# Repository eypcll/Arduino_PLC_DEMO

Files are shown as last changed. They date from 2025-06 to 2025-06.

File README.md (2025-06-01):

# Arduino_PLC_DEMO
Demo project for PLC with Arduino Nano
# ÖNSÖZ
PLC'ler (Programmable Logic Controllers), endüstriyel otomasyon süreçlerinde yaygın olarak kullanılan mikroişlemci tabanlı cihazlardır. Fabrika makinelerini, üretim hatlarını ve diğer otomasyon sistemlerini kontrol etmek için tasarlanmışlardır. PLC’ler, programlanabilir oldukları için farklı görevlerde kullanılabilirler ve elektrik devrelerine benzer mantık kontrolü sağlarlar. Dayanıklı yapıları sayesinde zorlu endüstriyel ortamlarda uzun süre çalışabilirler. Sensörlerden gelen verileri toplar, işleyerek motorları, vanaları veya diğer cihazları çalıştırır. Böylece üretim süreçlerini daha güvenli, verimli ve esnek hale getirirler. PLC dersini açan ve bize sunan sayın Y. Doç. Dr. Tuncay UZUN hocamıza teşekkür ederim.

# Abstract

This study involves the design of a PLC system built on the Arduino Nano using the ATmega328p microcontroller. The system includes both hardware and software components. It has been designed to be suitable for industrial use, with customizable software and easily accessible I/O ports. The project has been presented for the benefit of anyone interested in PLCs.
Keywords: PLC, Arduino, ATmega328, Relay





Demo yazılımın içerdiği operand listesi yukarıdaki tabloda verilmiştir. Buton 1 e basıldığında motor dönmektedir. Buton4 ile 5 e kadar counter saymaktadır sonucunda ise 203 çıkış rölesi aktif olmaktadır. Buton3 ise counter resetlemektedir. Buton 2 ise 201 röle çıkışını aktif etmektedir.

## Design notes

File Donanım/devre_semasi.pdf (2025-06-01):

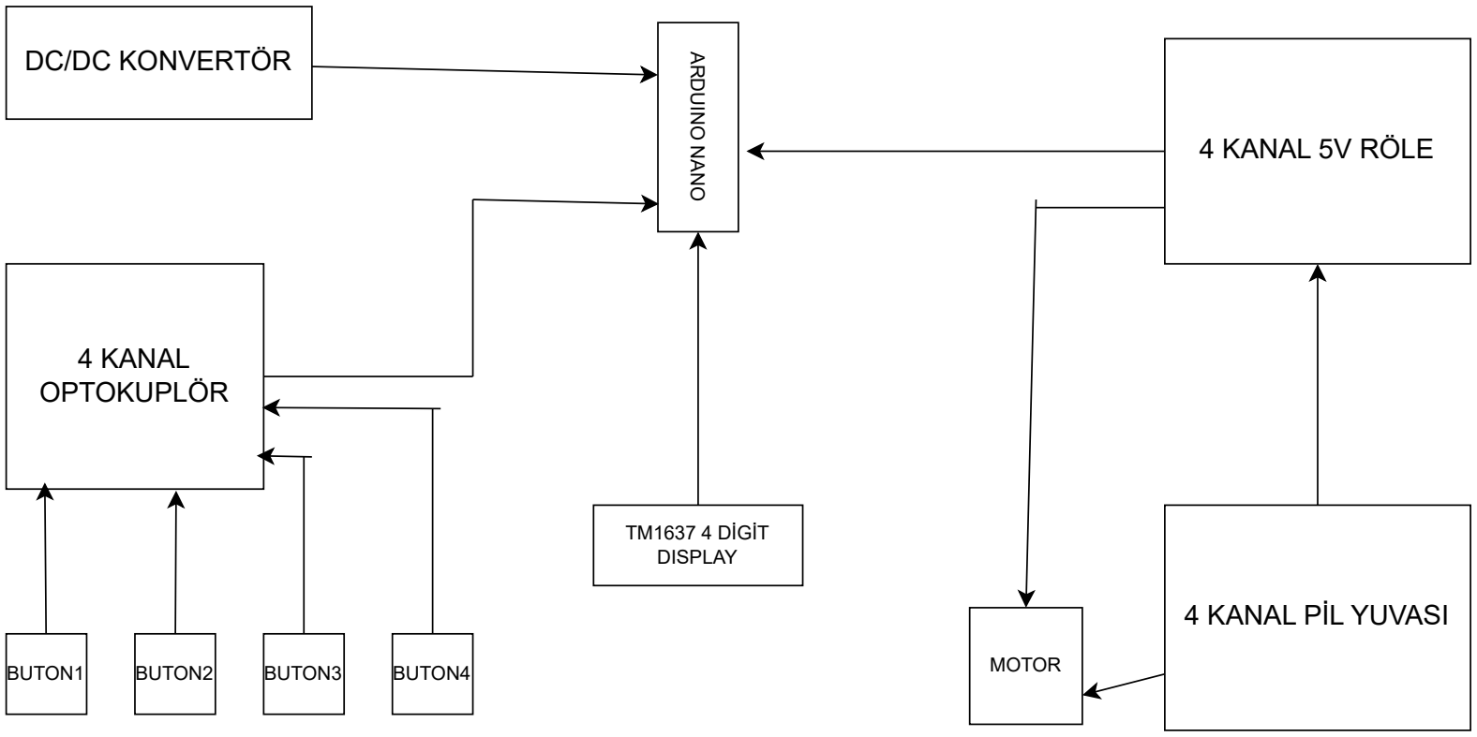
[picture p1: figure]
4 KANAL 5V RÖLE; 4 KANAL PİL YUVASI; DC/DC KONVERTÖR; 4 KANAL OPTOKUPLÖR; BUTON1; BUTON2; BUTON3; BUTON4; TM1637 4 DİGİT; DISPLAY ARDUINO NANO; MOTOR

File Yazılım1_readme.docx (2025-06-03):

Demo Yazılım 1

### Instruction List Breakdown

| Instruction | Address/Data | Description |

| LOD | 0 | Load value 0 |

| ORLOAD | 2 | Orload value 2 |

| ANDLOAD | 1 | Andload value 1 |

| ORLOAD | 3 | Orload value 3 |

| OUT | 200 | Output to address 200 |

### LADDER DIAGRAM Breakdown

|----[ ]----[ ]----( )----| // 0 AND 1 → 200

| 0 1 200 |

|----[ ]----[ ]----( )----| // 2 AND 1 → 200

| 2 1 200 |

|----[ ]----( )----| // 3 → 200

| 3 200 |

#include "PLC.h"

PLC plc;

void setup() {

Serial.begin(9600); // open the serial port at 9600 bps:

plc.init();

delay(1500);//Delay to let system boot

}

void loop() {

plc.load(0);

plc.orload(2);

plc.andload(1);

plc.orload(3);

plc.out(200);

}

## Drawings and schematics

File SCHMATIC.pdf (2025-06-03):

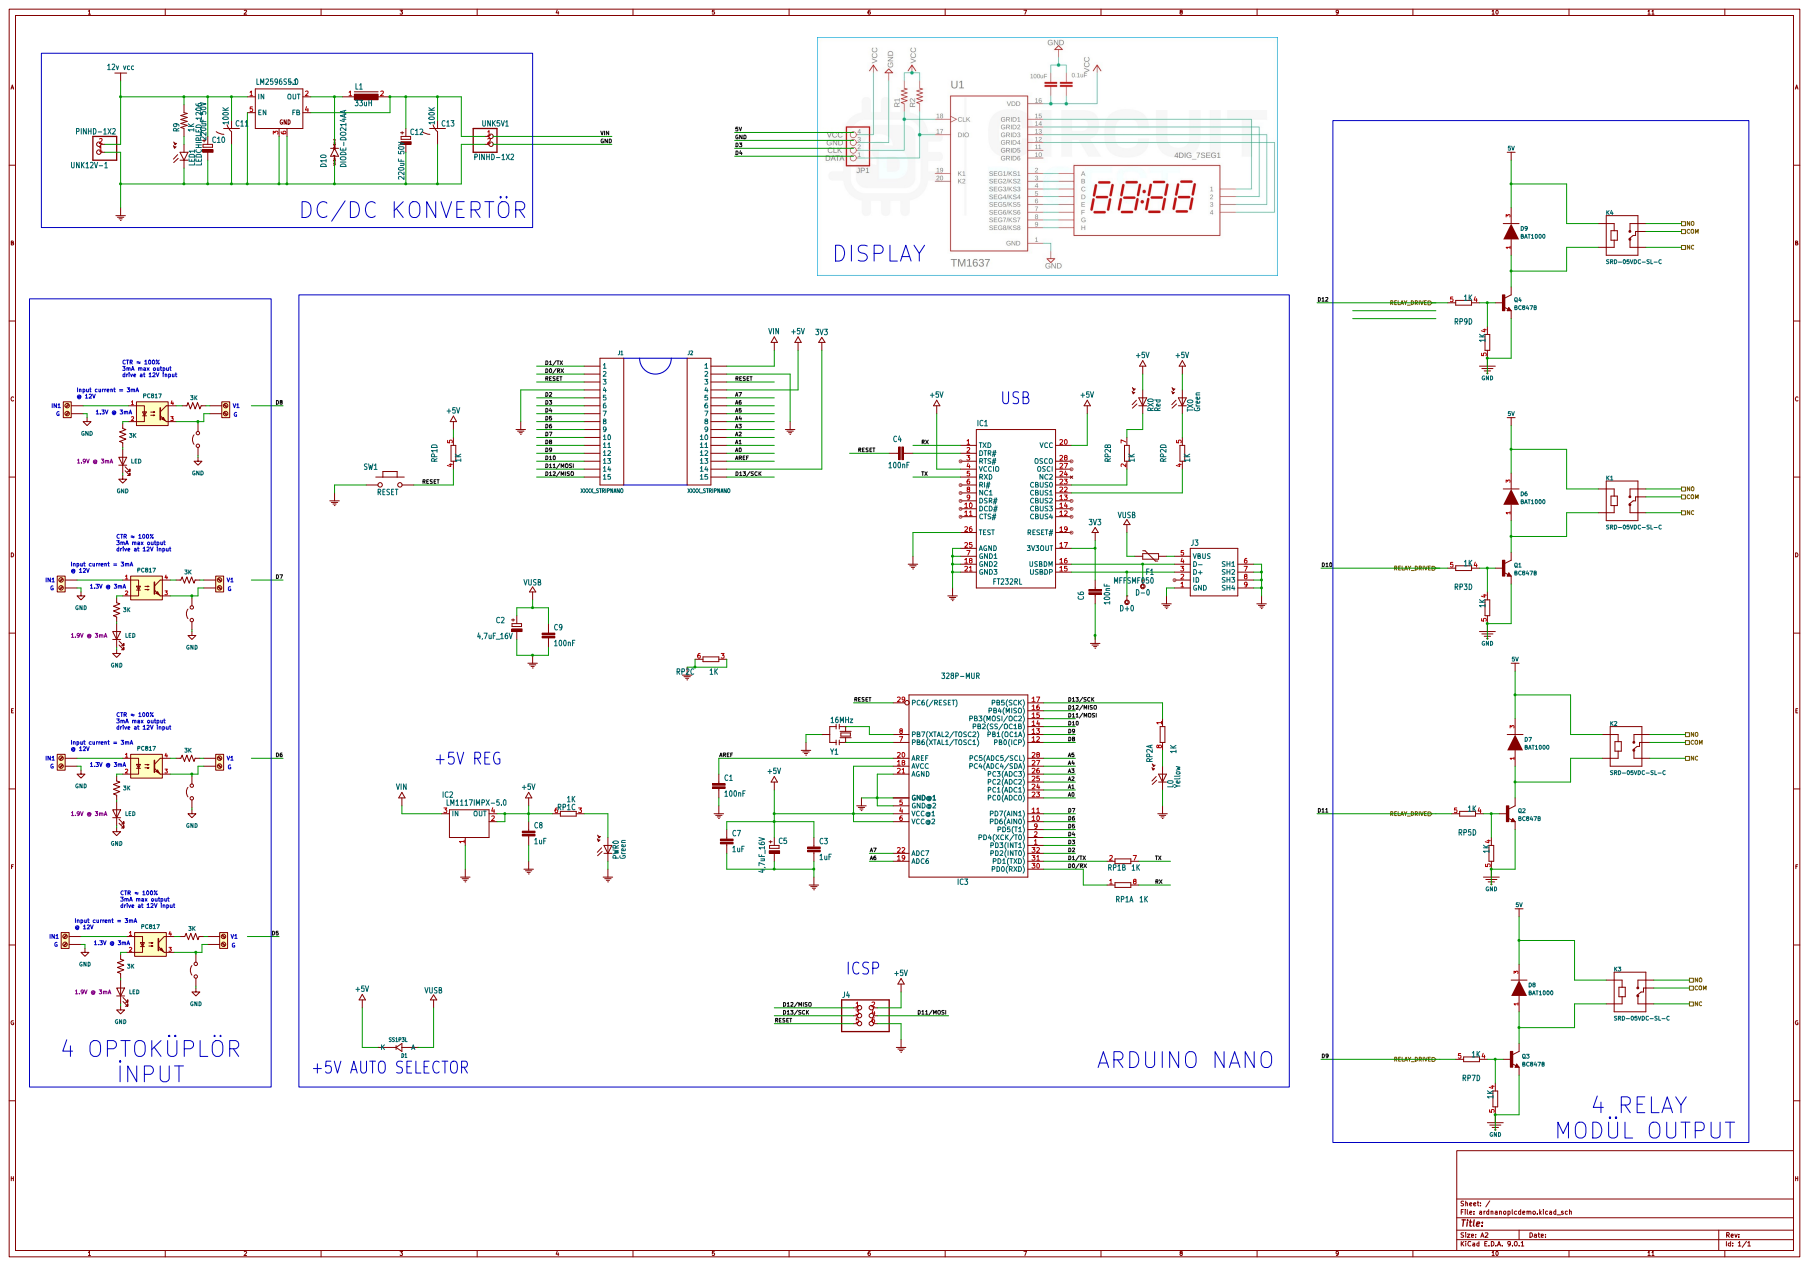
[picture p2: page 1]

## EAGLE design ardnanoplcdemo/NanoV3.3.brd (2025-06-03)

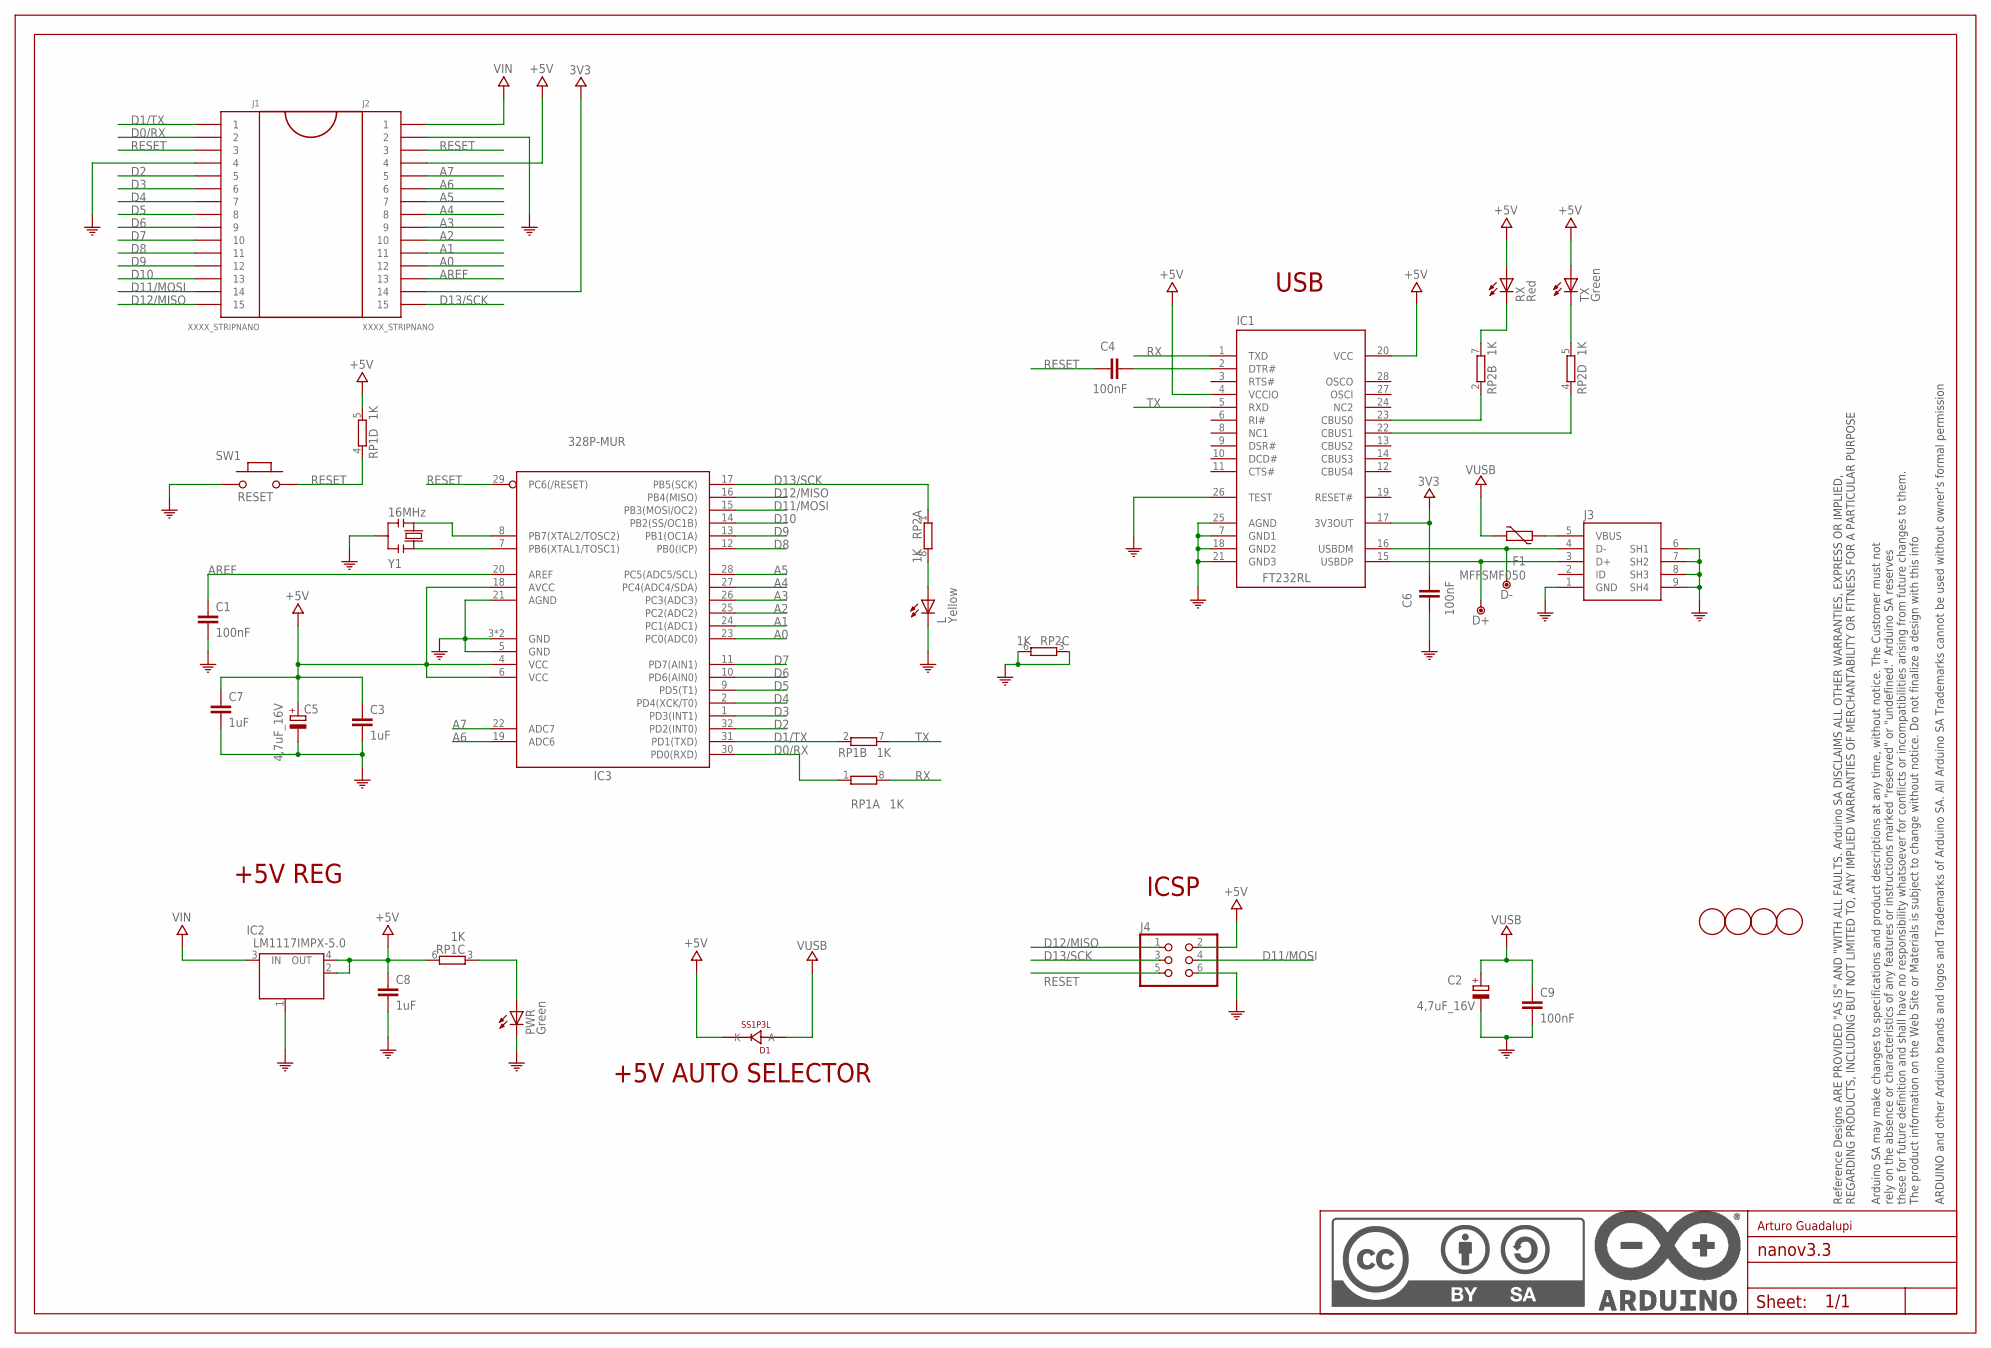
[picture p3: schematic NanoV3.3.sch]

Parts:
C1, C4, C6, C9: 100nF; C0603-ROUND
C2, C5: 4,7uF_16V; TAN-A
C3, C7, C8: 1uF; C0603-ROUND
D1: SS1P3L; DO220AAL
D+: DNP; TP-1.00MM
D-: DNP; TP-1.00MM
F1: MFFSMF050; 0603-1608X90N
FRAME1: DNP; FRAME
IC1: FT232RL; SSOP28
IC2: LM1117IMPX-5.0; LINEAR_SOT223
IC3: 328P-MUR; VQFN32
J1, J2: XXXX_STRIPNANO; HEAD15-NOSS
J3: 0219_14850; USB-MINI-B_2
J4: 0114_PH254-203DF118A00V; 2X03
L: Yellow; CHIPLED_0805
PWR: Green; CHIPLED_0805
RP1, RP2: 1K; CAY16
RX: Red; CHIPLED_0805
SW1: RESET; SMD_157SW
TX: Green; CHIPLED_0805
U$4, U$5, U$53, U$54: DNP; FD-1-1.5
Y1: 16MHz; RESONATOR

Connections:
3V3: C6.2, IC1.17 (3V3OUT), J2.14
+5V: C3.1, C5.1 (+), C7.1, C8.1, D1.P$1 (K), IC1.4 (VCCIO), IC1.20 (VCC), IC2.2 (OUT), IC2.4 (OUT), IC3.4 (VCC), IC3.6 (VCC), IC3.18 (AVCC), J2.4, J4.2, RP1.5 (2), RP1.6 (2), RX.A, TX.A
A0: IC3.23 (PC0(ADC0)), J2.12
A1: IC3.24 (PC1(ADC1)), J2.11
A2: IC3.25 (PC2(ADC2)), J2.10
A3: IC3.26 (PC3(ADC3)), J2.9
A4: IC3.27 (PC4(ADC4/SDA)), J2.8
A5: IC3.28 (PC5(ADC5/SCL)), J2.7
A6: IC3.19 (ADC6), J2.6
A7: IC3.22 (ADC7), J2.5
AREF: C1.1, IC3.20 (AREF), J2.13
COM: C1.2, C2.2 (-), C3.2, C5.2 (-), C6.1, C7.2, C8.2, C9.2, IC1.7 (GND1), IC1.18 (GND2), IC1.21 (GND3), IC1.25 (AGND), IC1.26 (TEST), IC2.1 (GND/ADJ), IC3.3 (GND), IC3.5 (GND), IC3.21 (AGND), IC3.33 (GND), J1.4, J2.2, J3.1 (GND), J3.6 (SH1), J3.7 (SH2), J3.8 (SH3), J3.9 (SH4), J4.6, L.C, PWR.C, RP2.3 (1), RP2.6 (2), SW1.1, Y1.2
D0/RX: IC3.30 (PD0(RXD)), J1.2, RP1.1
D1/TX: IC3.31 (PD1(TXD)), J1.1, RP1.2 (1)
D2: IC3.32 (PD2(INT0)), J1.5
D3: IC3.1 (PD3(INT1)), J1.6
D4: IC3.2 (PD4(XCK/T0)), J1.7
D5: IC3.9 (PD5(T1)), J1.8
D6: IC3.10 (PD6(AIN0)), J1.9
D7: IC3.11 (PD7(AIN1)), J1.10
D8: IC3.12 (PB0(ICP)), J1.11
D9: IC3.13 (PB1(OC1A)), J1.12
D10: IC3.14 (PB2(SS/OC1B)), J1.13
D11/MOSI: IC3.15 (PB3(MOSI/OC2)), J1.14, J4.4
D12/MISO: IC3.16 (PB4(MISO)), J1.15, J4.1
D13/SCK: IC3.17 (PB5(SCK)), J2.15, J4.3, RP2.1
unnamed: IC3.8 (PB7(XTAL2/TOSC2)), Y1.3
unnamed: IC3.7 (PB6(XTAL1/TOSC1)), Y1.1
unnamed: PWR.A, RP1.3 (1)
unnamed: C4.2, IC1.2 (DTR#)
unnamed: D+.X, IC1.15 (USBDP), J3.3 (D+)
unnamed: D-.X, IC1.16 (USBDM), J3.4 (D-)
unnamed: L.A, RP2.8 (2)
unnamed: IC1.23 (CBUS0), RP2.2 (1)
unnamed: IC1.22 (CBUS1), RP2.4 (1)
unnamed: RP2.5 (2), TX.C
unnamed: F1.2, J3.5 (VBUS)
unnamed: RP2.7 (2), RX.C
RESET: C4.1, IC3.29 (PC6(/RESET)), J1.3, J2.3, J4.5, RP1.4 (1), SW1.2
RX: IC1.1 (TXD), RP1.8 (2)
TX: IC1.5 (RXD), RP1.7 (2)
VIN: IC2.3 (IN), J2.1
VUSB: C2.1 (+), C9.1, D1.P$2 (A), F1.1

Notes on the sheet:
+5V REG
ICSP
USB
+5V AUTO SELECTOR
Arturo Guadalupi



Board: 2 copper layers, 43.2 x 17.8 mm, 33 parts (17 on the bottom side), 43 nets.

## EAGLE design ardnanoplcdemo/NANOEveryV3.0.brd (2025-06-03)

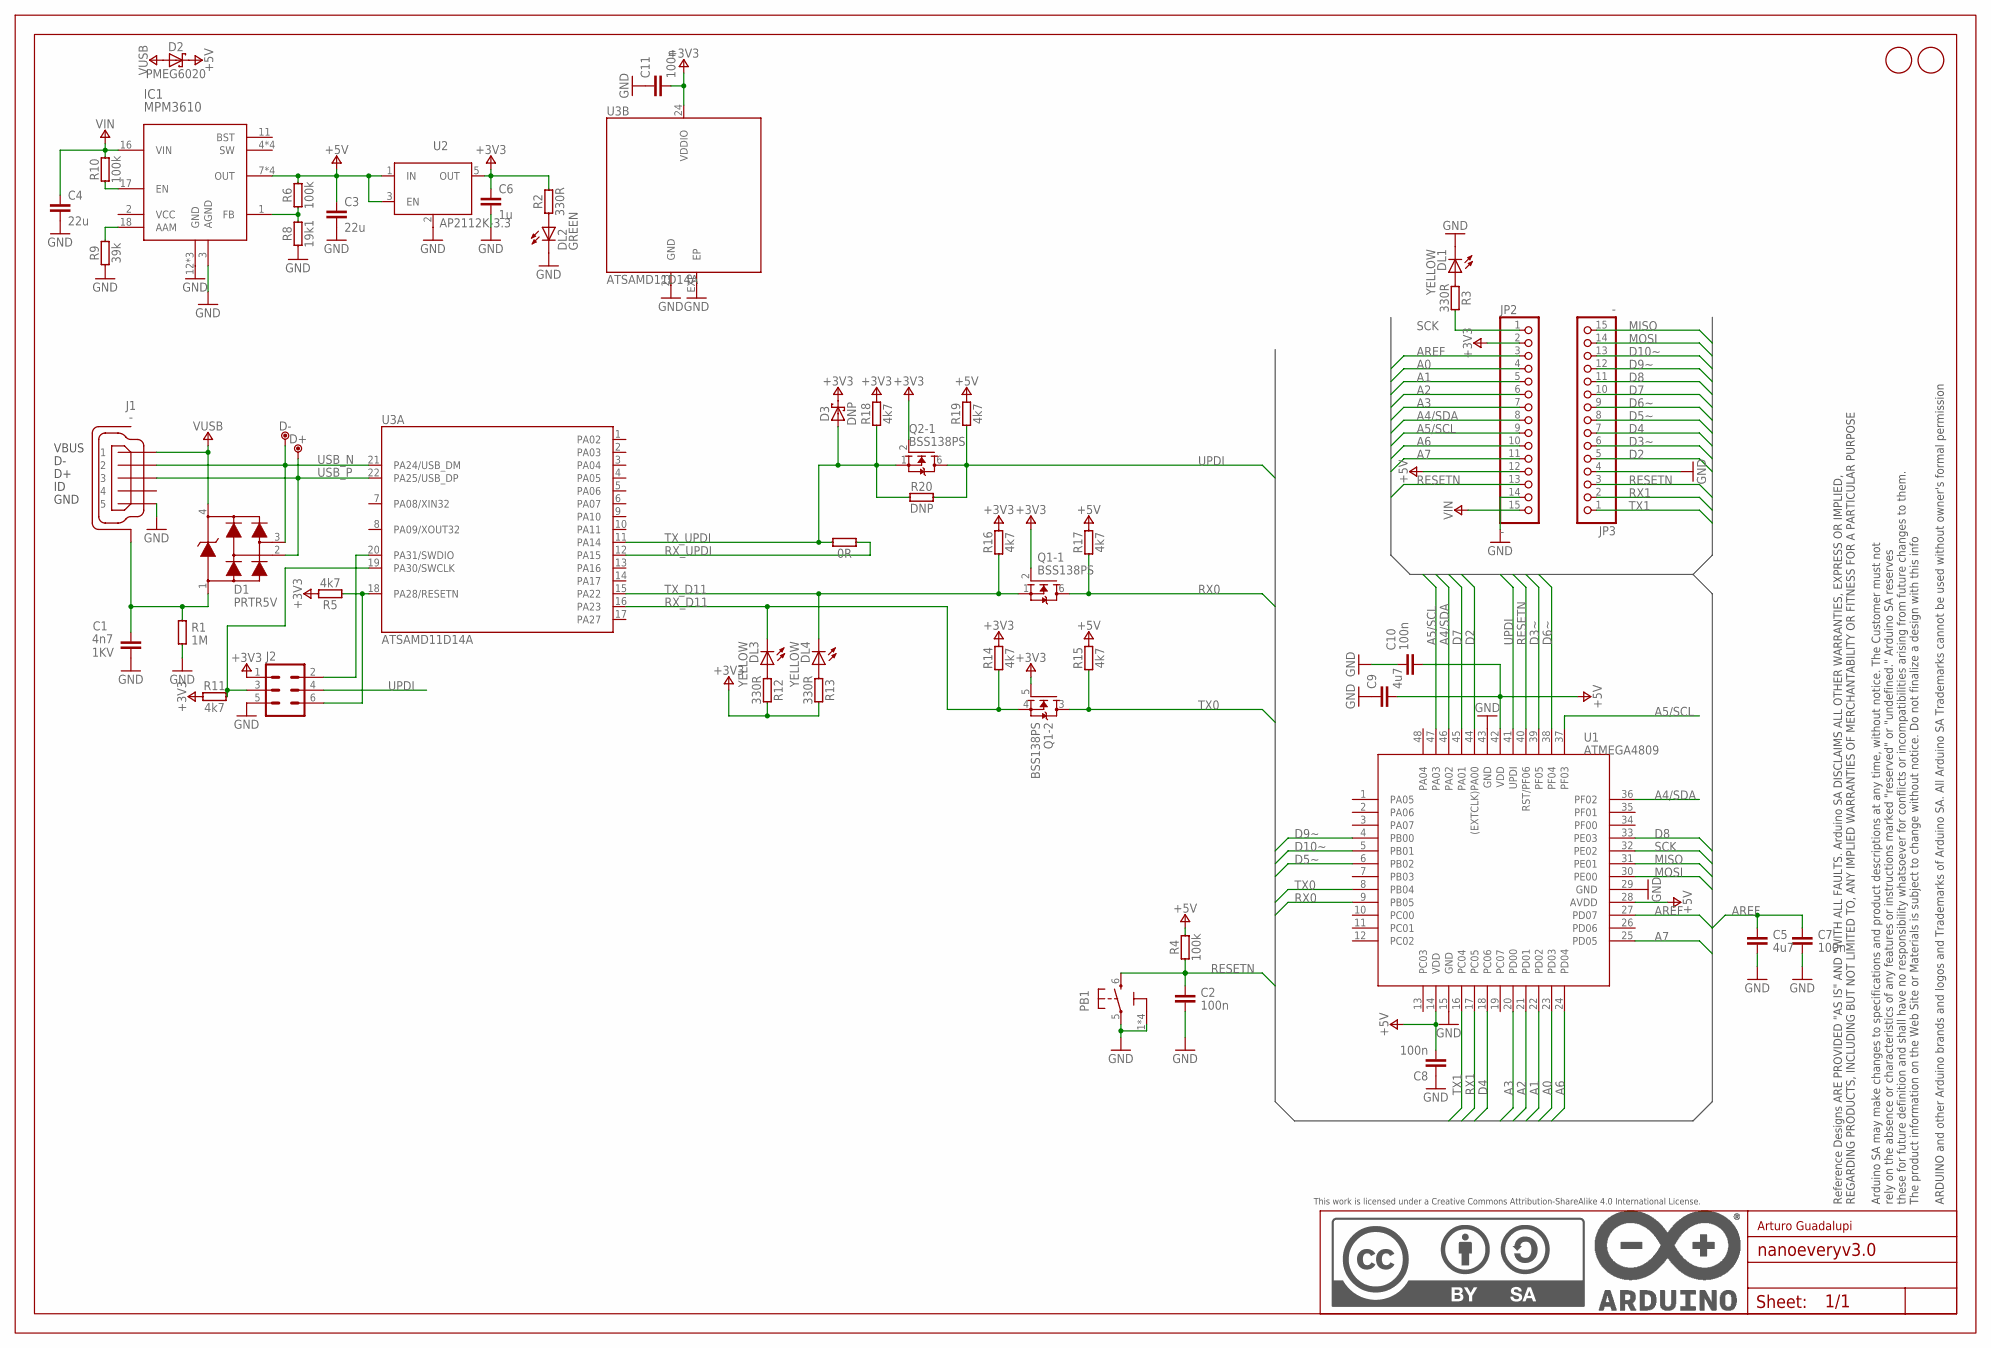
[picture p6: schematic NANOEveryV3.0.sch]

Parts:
C1: 4n7; 0805-R2013X50N; VOLTAGE 1KV
C2, C7, C8, C10, C11: 100n; 0402-1005X55N
C3, C4: 22u; 0805-R2013X50N
C5, C9: 4u7; 0402-1005X55N
C6: 1u; 0402-1005X55N
D1: PRTR5V; SOT190P230X110-4N
D2: PMEG6020; SODFL3517X110N
D3: DNP; SODFL3517X110N
D+: DNP; TP-1.00MM
D-: DNP; TP-1.00MM
DL1, DL3, DL4: YELLOW; LEDC1608X80N-AK
DL2: GREEN; LEDC1608X80N-AK
FD1, FD2: DNP; FD-1-1.5
FRAME1: DNP; FRAME
IC1: MPM3610
J1: -; ZX62-AB-5PA
J2: DNP; 2X03-TP
JP2, JP3: -; 1X15-CASTELL
PB1: PTS820; C&K_PTS820_NO_HOLES
Q1, Q2: BSS138PS; SOT363
R1: 1M; 0402-1005X55N
R2, R3, R12, R13: 330R; 0402-1005X55N
R4, R6, R10: 100k; 0402-1005X55N
R5, R11, R14, R15, R16, R17, R18, R19: 4k7; 0402-1005X55N
R7: 0R; 0402-1005X55N
R8: 19k1; 0402-1005X55N
R9: 39k; 0402-1005X55N
R20: DNP; 0402-1005X55N
U1: ATMEGA4809; TQFP48
U2: AP2112K-3.3; SOT25
U3: ATSAMD11D14A; HVQFN24

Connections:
+3V3: C6.1, C11.2, D3.C, J2.1, JP2.2, Q1.2 (G), Q1.5 (G), Q2.2 (G), R2.2, R5.2, R11.1, R12.2, R13.2, R14.2, R16.2, R18.2, U2.5 (OUT), U3.24 (VDDIO)
+5V: C3.1, C8.2, C9.2, C10.2, D2.C, IC1.7 (OUT), IC1.8 (OUT), IC1.9 (OUT), IC1.20 (OUT), JP2.12, R4.2, R6.2, R15.2, R17.2, R19.2, U1.14 (VDD), U1.28 (AVDD), U1.42 (VDD), U2.1 (IN), U2.3 (EN)
A0: JP2.4, U1.23 (PD03)
A1: JP2.5, U1.22 (PD02)
A2: JP2.6, U1.21 (PD01)
A3: JP2.7, U1.20 (PD00)
A4/SDA: JP2.8, U1.36 (PF02), U1.46 (PA02)
A5/SCL: JP2.9, U1.37 (PF03), U1.47 (PA03)
A6: JP2.10, U1.24 (PD04)
A7: JP2.11, U1.25 (PD05)
AREF: C5.1, C7.1, JP2.3, U1.27 (PD07)
D2: JP3.5, U1.44 ((EXTCLK)PA00)
D3~: JP3.6, U1.39 (PF05)
D4: JP3.7, U1.18 (PC06)
D5~: JP3.8, U1.6 (PB02)
D6~: JP3.9, U1.38 (PF04)
D7: JP3.10, U1.45 (PA01)
D8: JP3.11, U1.33 (PE03)
D9~: JP3.12, U1.4 (PB00)
D10~: JP3.13, U1.5 (PB01)
D11_RESET: J2.6, R5.1, U3.18 (PA28/RESETN)
D11_SWCLK: J2.3, R11.2, U3.19 (PA30/SWCLK)
D11_SWDIO: J2.2, U3.20 (PA31/SWDIO)
GND: C1.2, C2.2, C3.2, C4.2, C5.2, C6.2, C7.2, C8.1, C9.1, C10.1, C11.1, DL1.C, DL2.C, IC1.3 (AGND), IC1.12 (GND), IC1.13 (GND), IC1.14 (GND), J1.5, J2.5, JP2.14, JP3.4, PB1.1 (3), PB1.2 (3), PB1.3, PB1.4 (3), PB1.5 (1), R1.1, R8.1, R9.1, U1.15 (GND), U1.29 (GND), U1.43 (GND), U2.2 (GND/ADJ), U3.23 (GND), U3.EXP (EP)
MISO: JP3.15, U1.31 (PE01)
MOSI: JP3.14, U1.30 (PE00)
unnamed: C1.1, D1.1, J1.6 (SH), J1.7 (SH), J1.8 (SH), J1.9 (SH), J1.10 (SH), J1.11 (SH), R1.2
unnamed: DL2.A, R2.1
unnamed: DL1.A, R3.1
unnamed: IC1.1 (FB), R6.1, R8.2
unnamed: IC1.18 (AAM), R9.2
unnamed: IC1.17 (EN), R10.1
unnamed: DL3.A, R12.1
unnamed: DL4.A, R13.1
RESETN: C2.1, JP2.13, JP3.3, PB1.6 (2), R4.1, U1.40 (RST/PF06)
RX0: Q1.6 (D), R17.1, U1.9 (PB05)
RX1: JP3.2, U1.17 (PC05)
RX_D11: DL3.C, Q1.4 (S), R14.1, U3.16 (PA23)
RX_UPDI: R7.2, U3.12 (PA15)
SCK: JP2.1, R3.2, U1.32 (PE02)
TX0: Q1.3 (D), R15.1, U1.8 (PB04)
TX1: JP3.1, U1.16 (PC04)
TX_D11: DL4.C, Q1.1 (S), R16.1, U3.15 (PA22)
TX_UPDI: D3.A, Q2.1 (S), R7.1, R18.1, R20.1, U3.11 (PA14)
UPDI: J2.4, Q2.6 (D), R19.1, R20.2, U1.41 (UPDI)
USB_N: D1.3, D-.X, J1.2, U3.21 (PA24/USB_DM)
USB_P: D1.2, D+.X, J1.3, U3.22 (PA25/USB_DP)
VIN: C4.1, IC1.16 (VIN), JP2.15, R10.2
VUSB: D1.4, D2.A, J1.1

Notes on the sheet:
Arturo Guadalupi

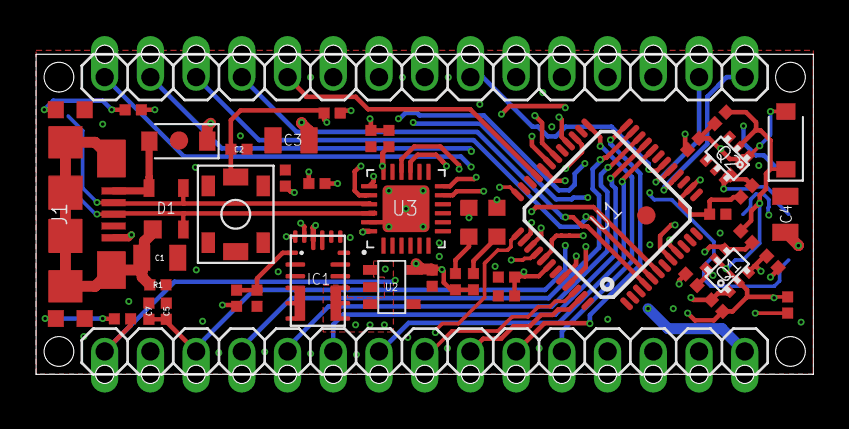
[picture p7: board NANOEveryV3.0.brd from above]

Board: 4 copper layers, 43.2 x 17.8 mm, 54 parts (0 on the bottom side), 49 nets.

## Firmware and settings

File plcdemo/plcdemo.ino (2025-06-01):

#include "PLC.h"

PLC plc;

void setup() {
  // put your setup code here, to run once:

Serial.begin(9600); // open the serial port at 9600 bps:


plc.init();
delay(1500);//Delay to let system boot

}

void loop() {
  // put your main code here, to run repeatedly:

    plc.load(0);
    plc.out(200);


  // plc.loadnot(0);
  // plc.andnotload(200);
  // plc.timer(100,100);
  // plc.out(200);
  
  // plc.loadnot(0);
  // plc.andnotload(201);
  // plc.timer(101,50);
  // plc.out(201);

  // plc.loadnot(0);
  // plc.andnotload(202);
  // plc.timer(102,150);
  // plc.out(202);
  
  // plc.loadnot(0);
  // plc.andnotload(203);
  // plc.timer(103,250);
  // plc.out(203);

  // plc.load(0);
  // plc.load(201);
  // plc.counter(900,10);
  // plc.load(900);
  // plc.func(147,25);

  /************************   and circuit 2   ***********************/

  // plc.load(0);
  // plc.orload(200);
  // andload(1);
  // andnotload(2);
  // plc.out(200);
  
  /************************   Multiple output circuit 1   ***********************/

  // load(0);
  // out(200);
  // andnotload(1);
  // out(201);
  // andload(2);
  // out(202);



  /************************   10 saniye timer    ***********************/
  // plc.loadnot(200);
  // plc.timer(100,100);
  // plc.out(200);
  // load(100);
  // func(147,25);


  /************************   buton ile 5 e kadar counter    ***********************/
  // plc.load(0);
  // load(1);
  // plc.load(200);
  // plc.counter(900,5);
  // plc.out(201);
  // plc.load(900);
  // plc.func(147,25);

}

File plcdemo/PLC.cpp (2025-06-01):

#include "PLC.h"
#include "TM1637.h"

static int digits[4] ;
TM1637 tm1637(CLK,DIO);

PLC::PLC(){};

void PLC::init()
{
  
pinMode(OUT_1, OUTPUT);
pinMode(OUT_2, OUTPUT);
pinMode(OUT_3, OUTPUT);
pinMode(OUT_4, OUTPUT);
digitalWrite(OUT_1,HIGH);
digitalWrite(OUT_2,HIGH);
digitalWrite(OUT_3,HIGH);
digitalWrite(OUT_4,HIGH);
pinMode(IN_1, INPUT_PULLUP);
pinMode(IN_2, INPUT_PULLUP);
pinMode(IN_3, INPUT_PULLUP);
pinMode(IN_4, INPUT_PULLUP);

tone(BuzzerPin,262);

tm1637.init();
tm1637.set(BRIGHT_TYPICAL); 
}


void PLC::reset()
{
  
  last_relay = 0;
  last_data = 0;
  current_relay = 0;
  current_data = 0;


  last_load = 0;
}


int* PLC::get_digits(uint32_t value)
{
  
  digits[0] = value/1000;
  digits[1] = value/100 - digits[0]*10;
  digits[2] = value/10 - digits[0]*100 - digits[1]*10;
  digits[3] = value - digits[0]*1000 - digits[1]*100 - digits[2]*10;
  return digits;
}

uint32_t PLC::get_data(uint32_t relay_number,bool old=false)
{
  int *res = get_digits(relay_number);

  last_relay = current_relay;
  current_relay = relay_number;
  switch(res[1])
  {
    case 0:
    if (old == true){return inputs[res[3]][3];}
    current_data = !digitalRead(inputs[res[3]][1]);
    set_data(relay_number);
    return current_data;
    break;
    case 1:
    if (old == true){return timers[res[3]][2];}
    return timers[res[3]][1];
    break;
    case 2:
    if (old == true){return output_relays[res[3]][3];}
    return output_relays[res[3]][2];
    break;
    case 3:
    break;
    case 4:
    if (old == true){return internal_relays[res[3]][2];}
    return internal_relays[res[3]][1];
    break;
    case 8:
    if (old == true){return data_register[res[3]][2];}
    return data_register[res[3]][1];
    break;
    case 9:
    if (old == true){return counters[res[3]][2];}
    return counters[res[3]][1];
    break;
  }

  return 1;
}

void PLC::set_data(uint32_t relay_number)
{
  int *res = get_digits(relay_number);

  switch(res[1])
  {
    case 0:
    if (current_data != inputs[res[3]][2]) {
      inputs[res[3]][3] = inputs[res[3]][2];
      inputs[res[3]][2] = current_data;
      }
    break;
    case 1:
    if (current_data != timers[res[3]][1]) {
      timers[res[3]][2] = timers[res[3]][1];
      timers[res[3]][1] = current_data;
      }
    break;
    case 2:
    if (current_data==1) {digitalWrite(output_relays[res[3]][1],LOW);} 
    else {digitalWrite(output_relays[res[3]][1],HIGH);}
    if (current_data != output_relays[res[3]][2]) {
      output_relays[res[3]][3] = output_relays[res[3]][2];
      output_relays[res[3]][2] = current_data;
      }
    break;
    case 3:
    break;
    case 4:
    if (current_data != internal_relays[res[3]][1]) {
      internal_relays[res[3]][2] = internal_relays[res[3]][1];
      internal_relays[res[3]][1] = current_data;
      }
    break;
    case 8:
    if (current_data != data_register[res[3]][1]) {
      data_register[res[3]][2] = data_register[res[3]][1];
      data_register[res[3]][1] = current_data;
      }
    break;
    case 9:
    if (current_data != counters[res[3]][1]) {
      counters[res[3]][2] = counters[res[3]][1];
      counters[res[3]][1] = current_data;
      }
    break;
  }

}

void PLC::display(uint32_t value)
{
  int *res = get_digits(value);
  tm1637.display(0,res[0]);
  tm1637.display(1,res[1]);
  tm1637.display(2,res[2]);
  tm1637.display(3,res[3]);
}

void PLC::out(uint32_t relay_number)
{
  set_data(relay_number);
}

uint32_t PLC::__and(uint32_t f,uint32_t s)
{
  if ((f == 1) && (s == 1)){return 1;}
  else{return 0;}
}

uint32_t PLC::__or(uint32_t f,uint32_t s)
{
  if ((f == 1) || (s == 1)){return 1;}
  else{return 0;}
}

uint32_t PLC::__not(uint32_t f) {return !f;}

void PLC::load(uint32_t select_relay)
{
  last_data = current_data;
  current_data = get_data(select_relay);
  last_load = current_data;
}
void PLC::loadnot(uint32_t select_relay)
{
  load(select_relay);
  last_load = __not(last_load);
  current_data = last_load;
}


void PLC::orload(uint32_t select_relay)
{
  uint32_t temp_load = last_load;
  load(select_relay);
  last_load = __or(temp_load,last_load);
  current_data = last_load;
}

void PLC::andload(uint32_t select_relay)
{
  uint32_t temp_load = last_load;
  load(select_relay);
  last_load = __and(temp_load,last_load);
  current_data = last_load;
}

void PLC::andnotload(uint32_t select_relay)
{
  uint32_t temp_load = last_load;
  loadnot(select_relay);
  last_load = __and(temp_load,last_load);
  current_data = last_load;
}

void PLC::ornotload(uint32_t select_relay)
{
  uint32_t temp_load = last_load;
  loadnot(select_relay);
  last_load = __or(temp_load,last_load);
  current_data = last_load;
}


void PLC::func(uint32_t func_relay,int func_number)
{

  switch(func_relay)
  {
    case 147:
      switch(func_number)
      {
          case 18: // increment
          current_data = get_data(current_relay);
          current_data +=1;
          if ((current_data <0) || (current_data>9999)) {current_data = 0;}
          set_data(current_relay);
          break;
          case 19: // decrement
          current_data = get_data(current_relay);
          current_data -=1;
          if ((current_data <0) || (current_data>9999)) {current_data = 0;}
          set_data(current_relay);
          break; 
          case 20: // store data
          set_data(current_relay);
          break; 
          case 25: // display
          display(current_data);
          break; 
      }

    
    break;
    default:
    break;
  }
}

void PLC::counter(int counter_relay_number , uint32_t preset_value,bool latch=true)
{
  int reset = last_data;
  int pulse = current_data;
  int old_pulse =0;
  if (latch == true) {old_pulse = get_data(current_relay,true);}
  
  load(counter_relay_number);
  if (reset == 1) {current_data = 0 ;func(147,20);}
  else if ((pulse == 1)&&(old_pulse == 0)) {func(147,18);func(147,20);}

  load(counter_relay_number);
  if (current_data == preset_value) {current_data = 1;}
  else if (current_data > preset_value) {current_data = 0 ;func(147,20);}
  else {current_data=0;}


}


unsigned long PLC::get_timer_ts(uint32_t timer_number)
{
  if (timer_number == 100) return Timer1;
  else if (timer_number == 101) return Timer2;
  else if (timer_number == 102) return Timer3;
  else if (timer_number == 103) return Timer4;
}
void PLC::set_timer_ts(uint32_t timer_number , unsigned long ts)
{
  if (timer_number == 100) Timer1 = ts;
  else if (timer_number == 101) Timer2 = ts;
  else if (timer_number == 102) Timer3 = ts;
  else if (timer_number == 103) Timer4 = ts;
}
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

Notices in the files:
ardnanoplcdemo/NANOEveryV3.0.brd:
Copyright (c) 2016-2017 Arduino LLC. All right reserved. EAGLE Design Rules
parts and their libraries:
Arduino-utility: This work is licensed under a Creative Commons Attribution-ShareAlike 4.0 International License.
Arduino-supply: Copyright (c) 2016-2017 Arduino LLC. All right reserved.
